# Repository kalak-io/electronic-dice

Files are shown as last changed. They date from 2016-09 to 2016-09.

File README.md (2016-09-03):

#D++

This is the electronic Project in 42 school made by [MDEKEN] (https://github.com/madeka)/ [DBISCHOF] (https://github.com/DimitriBischoff)/ [CJACQUEM] (https://github.com/kalak-io)

Great players we are, we love discovering new games. Most games require at least one dice if not other accessories. As part of the electronic program offered at the school 42, we wanted to design the object that would fit in all our games.

##Features

- Simple dice from 1 to 999
- Multiple dices from 1 to 9
- Countdown
- Chronometer

During six months, we learned :
- [x] to choose the right components ;
- [x] to draw the schematics ;
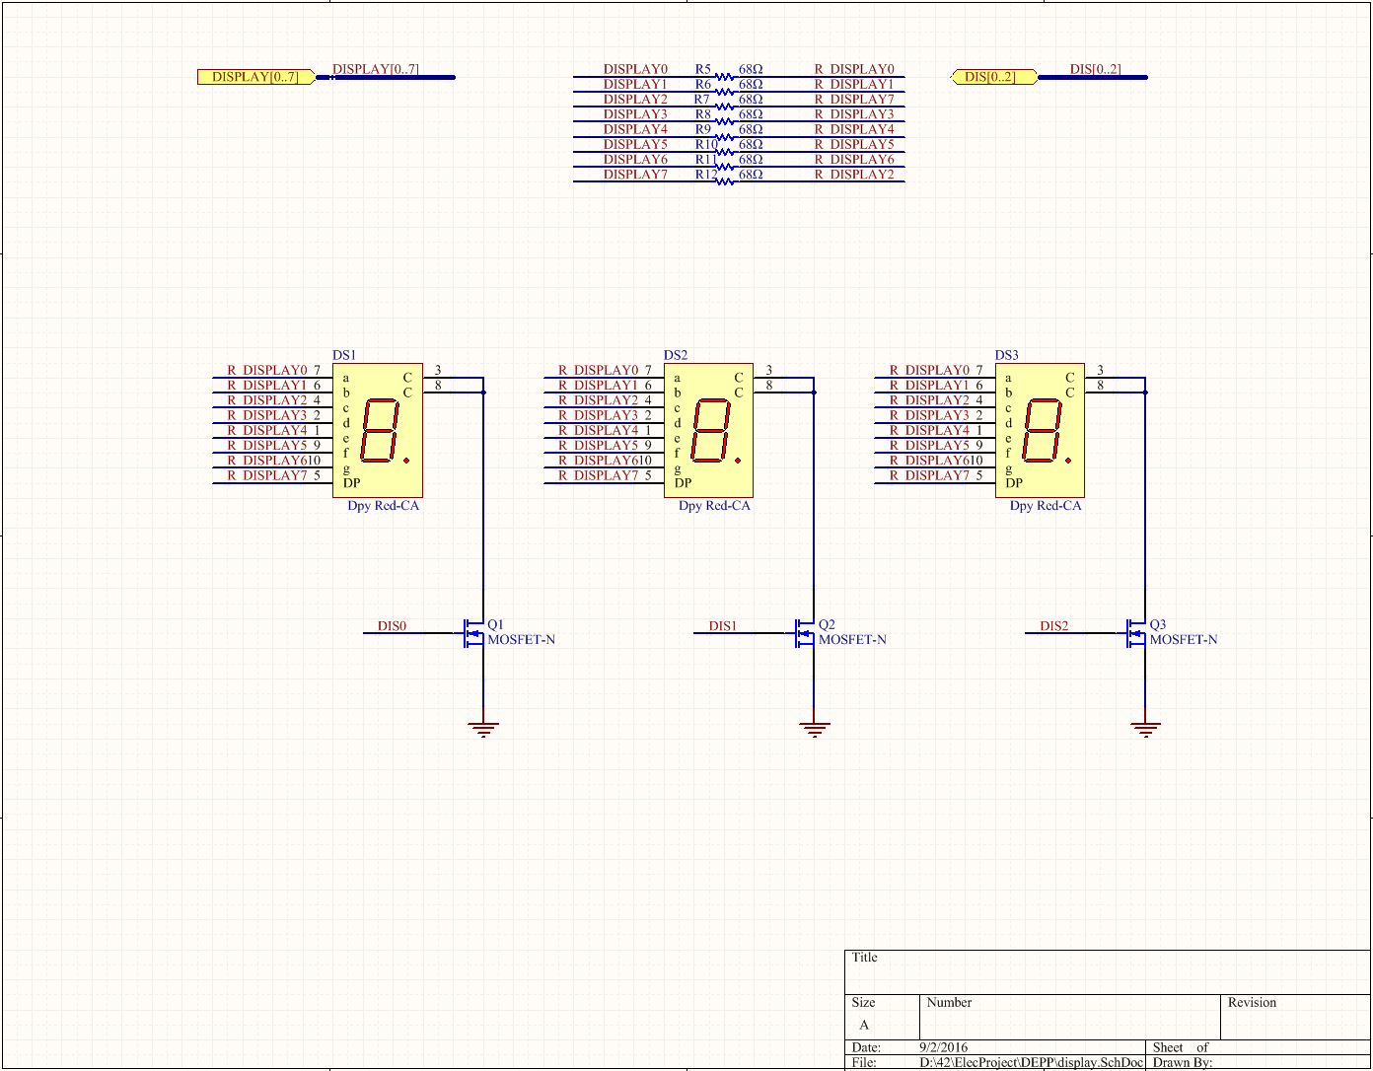
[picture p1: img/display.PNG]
Schematic

Schematics display
- [x] to design our own printed circuit board ;
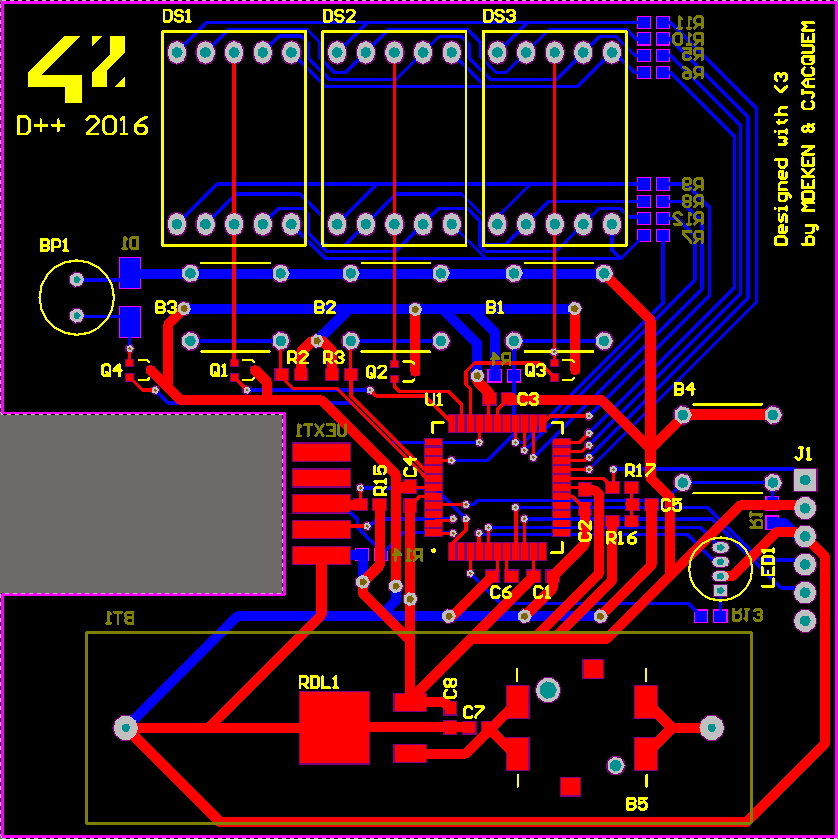
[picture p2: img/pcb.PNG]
pcb

- [x] to solder the components ;
- [x] to develop the features in C language ;
- [x] to test and to fix the code.

__We are happy to share with the community our work and we hope you'll have as much fun we had.__

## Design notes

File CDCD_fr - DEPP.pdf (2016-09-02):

D++

# Cahier des charges

élaboré dans le cadre du module d’électronique dispensé par Grégoire de

Turckheim au premier semestre 2016 à l’école 42

## Équipe

Dimitri Bischoff Madison Deken Clément Jacquemaire

D++

Cahier des charges | * | 2 / 8

INTRODUCTION

Grands joueurs de jeux de société, nous adorons découvrir de nouveau jeu voire d’en

créer. La plupart des jeux de société auxquels nous jouons nécessite au moins un dé si

ce n'est d'autres accessoires tel qu'un sablier. Dans le cadre du programme d'électronique

proposé à l'école 42, nous avons eu envie de concevoir l'objet qui permettrait de s'adapter

à tous nos jeux. Notre idée est un objet électronique pour nos activités ludiques qui devra

intégrer les fonctionnalités suivantes :

- Reproduire le comportement de un à trois dés gradués de 0 à 9 ;
- Avoir un chronomètre avec un temps maximal de 15 minutes ;
- Avoir un compte-à-rebours de 1 à 900 secondes, soit 15 minutes ;
- Émettre un son lors du lancer de dés et à la fin du compte-à-rebours.

Chacune de ces fonctionnalités sera exécutée seule. Il n'y aura pas de prise en charge

du multitâches. La sélection d'une fonctionnalité se fera par une interface de

paramétrages.

Les contraintes techniques posées sont :

- Miniaturiser au maximum notre objet pour qu'il soit transportable et à l'échelle

commune des accessoires de jeux de société ;

- Résister aux chocs d'intensité moyenne et aux accélérations ;
- Générer des résultats aléatoires pour chacun des afficheurs/dés ;
- Définir quand le calcul de l'aléatoire commence et s'arrête, sans doute dès qu'il est

mis en mouvement et quand il se stabilise.

EXPRESSION FONCTIONELLE

Notre objet comprendra quatre modes :

- un "dé simple" dont la plage des résultats potentiels est de 1 à 999 ;
- un "dé multiple" dont le nombre de dés activés peut varier de 1 à 3 et dont leur

plage des résultats potentiels varie de 1 à 9 ;

- un "chronomètre" ;
- un "compte-à-rebours".

À l'initialisation, le mode par défaut est celui du "dé simple".

Un bouton poussoir permet de choisir un mode différent. La progression dans les choix

possibles est signalée par une LED multicolore. Chaque mode ayant sa propre couleur

qui reste à définir.

Pour correspondre aux besoins de l'utilisateur, les modes "dé simple", "dé multiple" et

"compte-à-rebours" sont paramétrables.

DÉ SIMPLE

Par défaut, la plage des résultats potentiels s'étend de 1 à 6, soit les deux afficheurs de

gauche mis à zéro.

Pour modifier ce paramètre, l'utilisateur peut incrémenter la valeur maximale grâce à un

bouton situé sous chaque afficheur. Un premier clic de sécurité accompagné d'une

notification sonore suivi du clignotement de l'afficheur visé signifie à l'utilisateur qu'il peut

modifier la valeur maximale.

L'afficheur le plus à gauche modifie les centaines, celui du milieu les dizaines, celui de

droite les unités.

Leur plage de sélection s'étend de 0 à 9. Une incrémentation au-dessus de 9 fait repartir

l'affichage à 0.

Un lancer de dé permet de générer un nombre aléatoire dans la plage de résultats

potentiels entre 1 et X, X étant le nombre paramétré par l'utilisateur.

DÉ MULTIPLE

Par défaut, le nombre de dés activés est de 3 et la plage des résultats potentiels s'étend

de 1 à 6.

Pour modifier ces paramètres, l'utilisateur peut incrémenter la valeur maximale grâce à

un bouton situé sous chaque afficheur. Un premier clic de sécurité accompagné d'une

notification sonore suivi du clignotement de l'afficheur visé signifie à l'utilisateur qu'il peut

modifier la valeur maximale.

L'afficheur le plus à gauche modifie le premier dé, celui du milieu le deuxième dé, celui

de droite le dernier dé.

Leur plage de sélection s'étend de 0 à 9. Une incrémentation au-dessus de 9 fait repartir

l'affichage à 0. Un choix à 0 suspend le calcul de l'aléatoire pour cet afficheur / dé.

Un lancer de dé permet de générer un chiffre aléatoire pour chaque aléatoire dans la

plage de résultats potentiels entre 1 et X, X étant le chiffre paramétré par l'utilisateur. Les

plages sont indépendantes les unes des autres. Le premier dé peut aller de 1 à 6, le

deuxième de 1 à 4 et le dernier de 1 à 9.

COMPTE-À-REBOURS

Par défaut, le temps à décompter est de 30 secondes.

Pour modifier ce paramètre, l'utilisateur peut incrémenter la valeur maximale grâce à un

bouton situé sous chaque afficheur. Un premier clic de sécurité accompagné d'une

notification sonore suivi du clignotement de l'afficheur visé signifie à l'utilisateur qu'il peut

modifier la valeur maximale.

L'afficheur le plus à gauche modifie le nombre de minutes, celui du milieu les dizaines de

secondes, celui de droite les unités.

Leur plage de sélection s'étend de 0 à 9 pour l'afficheur de gauche et de droite ; l'afficheur

du milieu allant de 0 à 5 compris. Une incrémentation au-dessus de leur valeur maximale

fait repartir l'affichage à 0.

Un lancer de dé permet de lancer le compte-à-rebours.

Arrivé à 0, un son retentit pendant deux secondes.

CHRONOMÈTRE

Par défaut, les afficheurs affichent 0.

Pour lancer le chronomètre, il suffit d'appuyer sur le bouton situé sous l'afficheur gauche,

pour mettre en pause, il faut appuyer sur le bouton situé sous l'afficheur du milieu, pour

réinitialiser le chronomètre, sur le bouton situé sous l'afficheur de droite.

Un son est émis quand on appuie sur un de ces boutons.

L'afficheur de gauche désigne les minutes écoulées, celui du centre les dizaines de

secondes écoulées, celui de droite les secondes.

Leur plage d'affichage s'étend de 0 à 9 pour l'afficheur de gauche et de droite ; l'afficheur

du milieu allant de 0 à 5 compris.

MODE D’EMPLOI

AVERTISSEMENT: Pour réduire les risques d’incendie et de secousse électrique, ne pas exposer cet

appareil à la pluie ni à l’humidité.

GUIDE DE PRISE EN MAIN

Avec ce dé, vous êtes prêt à vivre des parties enflammées de jeux de société. Il va vous permettre d’avoir

un dé affichant une valeur aléatoire de 1 à 999, jusqu’à 3 dés affichant une valeur aléatoire de 1 à 9, mais

aussi un compte-à-rebours et un chronomètre. Ce dé peut vous accompagner dans 999 jeux !

1. | Appuyez sur le bouton On/Off pour mettre en marche le dé.
2. | Choisissez le mode de votre choix en appuyant sur le bouton choix des modes. Il existe quatre modes : des dés, un compte-à-rebours et un chronomètre. Chaque mode est représenté par une couleur. Rouge => Compte-à-rebours Violet => Dé multiple Bleu => Dé simple Vert => Chronomètre
2.1 | MODE DÉ SIMPLE : Entrez dans le mode de configuration en appuyant sur le bouton correspondant au bon écran à modifier. Choisissez la valeur maximale de votre choix en incrémentant successivement les centaines, les dizaines et les unités. Lancez le dé pour obtenir une valeur.
2.2 | MODE DÉ MULTIPLE : Entrez dans le mode de configuration en appuyant sur le bouton correspondant au bon écran à modifier. Choisissez la valeur maximale de votre choix en incrémentant successivement chacun des dés. Lancez le dé pour obtenir des valeurs.
2.3 | MODE COMPTE-À-REBOURS : Entrez dans le mode de configuration en appuyant sur le bouton correspondant au bon écran à modifier. Choisissez la durée de votre choix en incrémentant successivement les minutes, les dizaines de secondes et les secondes. Lancez simplement le dé pour démarrer le compte-à-rebours. ATTENTION : le compte-à-rebours ne va pas au-delà de 9 minutes et 59 secondes.
2.4 | MODE CHRONOMÈTRE : Lancez le chronomètre en appuyant sur le bouton situé sous l’afficheur central. Faites pause en appuyant sur le bouton central et celui de droite pour réinitialiser le chronomètre. ATTENTION : le chronomètre ne va pas au-delà de 9 minutes et 59 secondes.

CONTENU DE LA BOITE

- Un dé électronique
- Un mode d’emploi

ATTENTION : Les éléments d’emballage tels que films plastiques, rubans adhésifs, étiquettes et rubans de

fixation métalliques ne font pas partie de ce jouet et doivent être enlevés pour raison de sécurité avant toute

utilisation par un enfant.

ALIMENTATION

Le dé fonctionne avec 1 pile lithium 3V7 de type AA (non fournie).

Ne pas recharger les piles non rechargeables. Retirer les accumulateurs du jeu avant de les recharger. Ne

charger les accumulateurs que sous la surveillance d’un adulte. Ne pas mélanger différents types de piles

ou accumulateurs, ou des piles et accumulateurs neufs et usagés. Les piles et accumulateurs doivent être

mis en place en respectant la polarité. Les piles et accumulateurs usagés doivent être enlevés du jouet.

Les bornes d’une pile ou d’un accumulateur ne doivent pas être mises en court-circuit. Ne pas jeter les piles

au feu. Retirer les piles en cas de non utilisation prolongée. ATTENTION : D’importantes interférences

électromagnétiques ou des décharges électrostatiques peuvent provoquer un dysfonctionnement ou une

perte de données. Si l’appareil ne fonctionne pas correctement, réinitialisez l’unité ou enlevez puis remettez

les piles.

ENTRETIEN

Protéger le dé de l’humidité. S’il est mouillé, l’essuyer immédiatement. Ne pas le laisser en plein soleil, ne

pas l’exposer à une source de chaleur. Ne pas le laisser tomber. Ne pas tenter de le démonter. Pour le

nettoyer, utiliser un chiffon légèrement imbibé d’eau à l’exclusion de tout produit détergent. En cas de

mauvais fonctionnement, essayez d’abord de changer les piles. Si le problème persiste, relisez

attentivement la notice afin de vérifier que rien ne vous a échappé.

GARANTIE

NOTE : Veuillez garder ce mode d’emploi, il contient d’importantes informations. Ce produit est couvert par

notre garantie de zéro année. Pour toute mise en œuvre de la garantie ou de service après-vente, vous

devez vous adresser à Grégoire. Notre garantie ne couvre pas les vices de matériel ou de montage

imputables au constructeur à l’exclusion de toute détérioration provenant du non-respect de la notice

d’utilisation ou toute intervention intempestive sur l’article (telle que le démontage, exposition à la chaleur

ou à l’humidité).

Il est recommandé de conserver l’emballage pour toute référence ultérieure. Dans un souci constant

d’amélioration, nous pouvons être amenés à modifier les couleurs et les détails du produit présenté sur

l’emballage. Avertissement ! Ce dé ne convient pas à un enfant de moins de 36 mois. Risque d’étouffement.

CONTACT

D++
96 boulevard Bessières
75017 Paris
France

Services consommateurs demandez Matthieu.

Informations sur la protection de l’environnement : Tout appareil électrique usé est une matière recyclable et

ne devrait pas faire partie des ordures ménagères! Nous vous demandons de bien vouloir nous soutenir en

contribuant activement au ménagement des ressources et à la protection de l’environnement en déposant cet

appareil dans des de collecte (si existants).

Conçu en France – Fabriqué en Chine

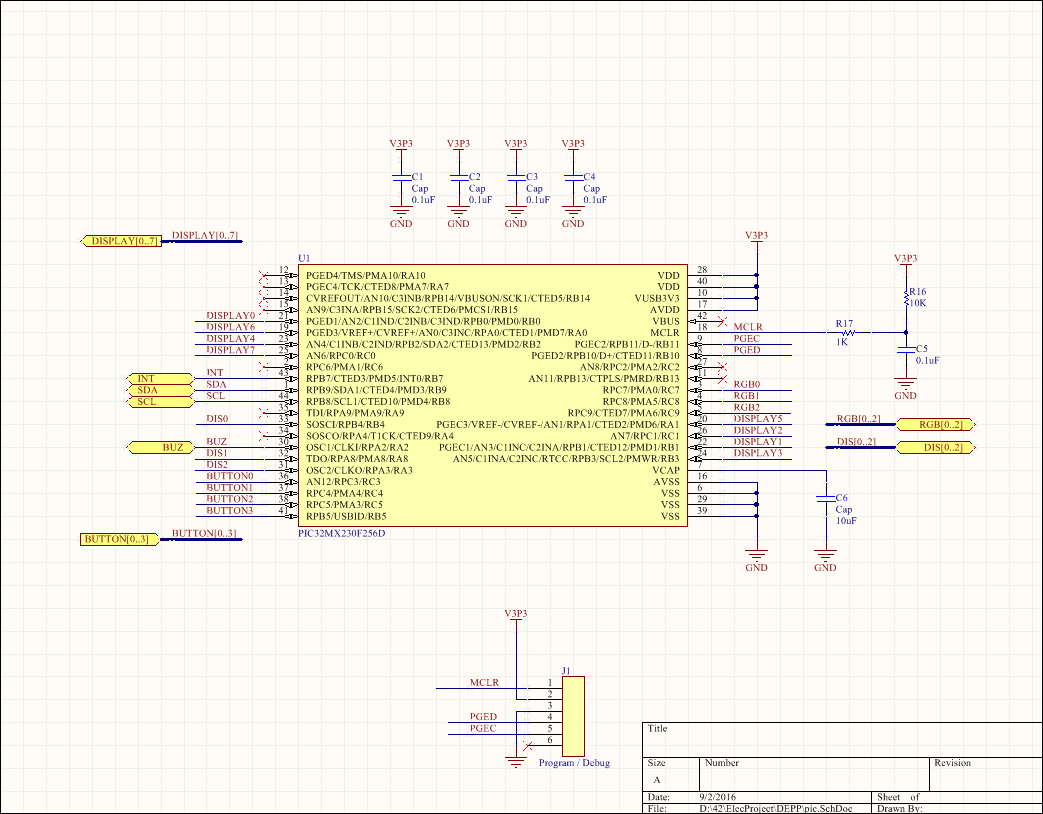
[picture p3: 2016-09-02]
img/schematic-pic.PNG

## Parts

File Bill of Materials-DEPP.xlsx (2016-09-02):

Comment | Description | Designator | Footprint | LibRef | Quantity | Fabricant | Fournisseur | Ref. fabricant | Ref. fournisseur
PIC32MX320F032H-40I/PT |  | U2 |  | PIC32MX320F032H-40I/PT | 1 | MICROCHIP | Farnell | PIC32MX320F032H-40I/PT | 1523318
Program / Debug |  | J1 | RJ12_90 | CON6 | 1 | Molex
Dpy Blue-CA | 14.2 mm General Purpose Blue 7-Segment Display: CA, RH DP, Gray Surface | DS1 | H | Dpy Blue-CA | 1 | AVAGO TECHNOLOGIES | Farnell | HDSM-433B | 1659317
Dpy Red-CA | 7.62 mm Black Surface HER 7-Segment Display: CA, RH DP | DS2 | A | Dpy Red-CA | 1 | AVAGO TECHNOLOGIES | Farnell | HDSM-433C | 1651429
Dpy Red-CA | 7.62 mm Black Surface HER 7-Segment Display: CA, RH DP | DS3 | A | Dpy Red-CA | 1 | AVAGO TECHNOLOGIES | Farnell | HDSM-433C | 1651429
MMA7660FC | Accelerometer | A1 |  | MMA7660FC | 1 | Freescale / NXP | Farnell | MMA7660FCT | 2238133
Buzzer Piezo | Buzzer piezo | BP1 | PIN2 | Speaker | 1 | PRO SIGNAL | Farnell | ABT-410-RC | 1022402
8MHz | Crystal Oscillator | Y1 | XTAL139X50X45 | XTAL | 1 | FOX ELECTRONICS | Farnell | FOXSDLF/080-20 | 2063972
'VLF302515MT-2R2M' | Inductance | L1 |  | 'VLF302515MT-2R2M' | 1 | TDK | Farnell | VLF302515MT-2R2M | 2455323
LED RGB | LED RGB pour les modes | LED |  | LED RGB | 1 | MULTICOMP | Farnell | 703-1028 | 2112143
3V | Multicell Battery | BT1 | BAT-2 | Battery | 1 | MULTICOMP | Farnell | CR2450 | 2065173
3V | Multicell Battery | BT2 | BAT-2 | Battery | 1 | MULTICOMP | Farnell | CR2450 | 2065173
MOSFET-N | N-Channel MOSFET | Q1 | E3 | MOSFET-N | 1 | NXP | Farnell | NX7002AKA | 2357126
MOSFET-N | N-Channel MOSFET | Q2 | E3 | MOSFET-N | 1 | NXP | Farnell | NX7002AKA | 2357126
MOSFET-N | N-Channel MOSFET | Q3 | E3 | MOSFET-N | 1 | NXP | Farnell | NX7002AKA | 2357126
TPS62150ARGTR | Regulateur a decouplage | U1 |  | TPS62150ARGTR | 1 | Texas Instruments | Farnell | TPS62150ARGTT | 2361248
SW-SPST | Single-Pole, Single-Throw Switch | S2 | SPST-2 | SW-SPST | 1 | C & K COMPONENTS | Farnell | PVB4 EE 300 NS LFS | 2435330
 | Support de pile |  |  | KEYSTONE 1025-7 BATTERY HOLDER PCB | 1 | KEYSTONE | Farnell | 1025-7 | 1650668
SW-PB | Switch | S1_BUTTON | SPST-2 | SW-PB | 1 | PANASONIC ELECTRONIC COMPONENTS | Farnell | ESE20C341 | 2079611
SW-PB | Switch | S1_BUTTON0 | SPST-2 | SW-PB | 1 | PANASONIC ELECTRONIC COMPONENTS | Farnell | ESE20C341 | 2079611
SW-PB | Switch | S1_BUTTON1 | SPST-2 | SW-PB | 1 | PANASONIC ELECTRONIC COMPONENTS | Farnell | ESE20C341 | 2079611
SW-PB | Switch | S1_BUTTON3 | SPST-2 | SW-PB | 1 | PANASONIC ELECTRONIC COMPONENTS | Farnell | ESE20C341 | 2079611

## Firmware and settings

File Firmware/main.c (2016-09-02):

#include "depp.h"
#include <p32xxxx.h>

u8 mode = SIMPLE;
u8 max_ds1 = 6;
u8 max_ds2 = 6;
u8 max_ds3 = 6;
u16 absolute_max = 6;
u8 current_ds1 = 0;
u8 current_ds2 = 0;
u8 current_ds3 = 6;
u8 current_time = 0;
u8 default_count = 30;
u8 default_min = 0;
u8 default_chrono = 0;
u8 chrono = 0;
u16 counter_tmr = 0;
u8 dp = 0;
u8 minute = 0;
u32 random_value1 = 0; //u32 in order to avoid overflow
u32 random_value2 = 0;
u32 random_value3 = 0;
s16 x = 0;
s16 y = 0;
s16 z = 0;
u8 blink = 0;

void set_number(u16 n) {
    current_ds1 = n / 100;
    current_ds2 = n % 100 / 10;
    current_ds3 = n % 10;
}

void show_result() {
    u8 result = 0;

    blink = 0;
    if (mode == SIMPLE) {
        if (absolute_max != 0) {
            random_value1 %= absolute_max;
            random_value2 %= absolute_max;
            random_value3 %= absolute_max;
            result = ((random_value1 + random_value2 + random_value3) % absolute_max) + 1;
            set_number(result);
        }
    } else if (mode == MULTI) {
        current_ds1 = (max_ds1 > 0) ? (random_value1 % max_ds1) + 1 : 0;
        current_ds2 = (max_ds2 > 0) ? (random_value2 % max_ds2) + 1 : 0;
        current_ds3 = (max_ds3 > 0) ? (random_value3 % max_ds3) + 1 : 0;
    } else if (mode == COUNTDOWN && chrono == 0) {
        chrono = 1;
    }
}

void __ISR(INT1_VECTOR, ipl1SOFT) Button2_handler(void) {
    while (PORTCbits.RC4 == 1);
    while (PORTCbits.RC4 == 1);
    counter_tmr = 0;
    if (mode == SIMPLE) {
        if (blink == 1) {
            ++current_ds2;
            if (current_ds2 >= 10)
                current_ds2 = 0;
            absolute_max = (current_ds1 * 100) + (current_ds2 * 10) + current_ds3;
            set_number(absolute_max);
        } else
        {
            blink = 1;
            set_number(absolute_max);
        }
    } else if (mode == MULTI) {
        if (blink == 1) {
            ++max_ds2;
            if (max_ds2 >= 10)
                max_ds2 = 0;
            set_number((max_ds1 * 100) + (max_ds2 * 10) + max_ds3);
        } else{
            blink = 1;
            set_number((max_ds1 * 100) + (max_ds2 * 10) + max_ds3);
        }
    } else if (mode == COUNTDOWN) {
        if (PORTCbits.RC5 == 1) {
            current_time = default_count;
            set_number(current_time);
        } else if (chrono == 0) {
            if (blink == 1) {
                ++current_ds2;
                if (current_ds2 >= 6)
                    current_ds2 = 0;
                default_count = (current_ds2 * 10) + current_ds3;
                current_time = default_count;
                set_number((default_min * 100) + default_count);
            } else{
                blink = 1;
                set_number((default_min * 100) + default_count);
            }
        }
    } else if (mode == CHRONO) {
        chrono = (chrono == 1) ? 0 : 1;
    }
    IFS0bits.INT1IF = 0;
}

void __ISR(INT2_VECTOR, ipl2SOFT) Button1_handler(void) {
    while (PORTCbits.RC3 == 1);
    while (PORTCbits.RC3 == 1);
    counter_tmr = 0;
    if (mode == SIMPLE) {
        if (blink == 1) {
            ++current_ds3;
            if (current_ds3 >= 10)
                current_ds3 = 0;
            absolute_max = (current_ds1 * 100) + (current_ds2 * 10) + current_ds3;
            set_number(absolute_max);
        } else
        {
            blink = 1;
            set_number(absolute_max);
        }
    } else if (mode == MULTI) {
        if (blink == 1) {
            ++max_ds3;
            if (max_ds3 >= 10)
                max_ds3 = 0;
            set_number((max_ds1 * 100) + (max_ds2 * 10) + max_ds3);
        } else{
            blink = 1;
            set_number((max_ds1 * 100) + (max_ds2 * 10) + max_ds3);
        }
    } else if (mode == COUNTDOWN) {
        if (chrono == 0) {
            if (blink == 1) {
                ++current_ds3;
                if (current_ds3 >= 10)
                    current_ds3 = 0;
                current_time = (current_ds2 * 10) + current_ds3;
                default_count = current_time;
                set_number((default_min * 100) + default_count);
            } else{
                blink = 1;
                set_number((default_min * 100) + default_count);
            }
        } else
            chrono = 0;
    }
    IFS0bits.INT2IF = 0;
}

void __ISR(INT3_VECTOR, ipl2SOFT) Mode_handler(void) {
    chrono = 0;
    blink = 0;
    while (PORTBbits.RB5 == 1);
    while (PORTBbits.RB5 == 1);
    mode = (mode + 1) % 4;
    if (mode == SIMPLE) {
        dp = 0;
        set_number(absolute_max);
        pwm_led(BLUE);
    } else if (mode == MULTI) {
        dp = 0;
        set_number((max_ds1 * 100) + (max_ds2 * 10) + max_ds3);
        pwm_led(PURPLE);
    } else if (mode == COUNTDOWN) {
        dp = 1;
        current_time = 30;
        counter_tmr = 0;
        set_number((default_min * 100) + default_count);
        pwm_led(RED);
    } else if (mode == CHRONO) {
        dp = 1;
        current_time = 0;
        counter_tmr = 0;
        set_number(default_chrono);
        pwm_led(GREEN);
    }
    while (PORTBbits.RB5 == 1);
    IFS0bits.INT3IF = 0;
}

void __ISR(INT4_VECTOR, ipl1SOFT) Button3_handler(void) {
    while (PORTCbits.RC5 == 1);
    while (PORTCbits.RC5 == 1);
    counter_tmr = 0;
    if (mode == SIMPLE) {
        if (blink == 1) {
            dp = 0;
            ++current_ds1;
            if (current_ds1 >= 10)
                current_ds1 = 0;
            absolute_max = (current_ds1 * 100) + (current_ds2 * 10) + current_ds3;
            set_number(absolute_max);
        } else{
            blink = 1;
            set_number(absolute_max);
        }
    } else if (mode == MULTI) {
        if (blink == 1) {
            dp = 0;
            ++max_ds1;
            if (max_ds1 >= 10)
                max_ds1 = 0;
            set_number((max_ds1 * 100) + (max_ds2 * 10) + max_ds3);
        } else{
            blink = 1;
            set_number((max_ds1 * 100) + (max_ds2 * 10) + max_ds3);
        }
    } else if (mode == COUNTDOWN) //reset to default value
    {
        if (PORTCbits.RC4 == 1) {
            current_time = default_count;
            set_number(current_time);
        } else if (chrono == 0) {
            if (blink == 1) {
                ++default_min;
                if (default_min >= 10)
                    default_min = 0;
                minute = default_min;
                set_number((default_min * 100) + (current_ds2 * 10) + current_ds3);
            } else{
                set_number((default_min * 100) + default_count);
                blink = 1;
            }
        }
    } else if (mode == CHRONO) //reset to default value
    {
        chrono = 0;
        current_time = 0;
        set_number(current_time);
    }
    IFS0bits.INT4IF = 0;
}

u8 mpu_is_shaking() {
    static u8 stock_stack = 0;
    u8 ret = 0;

    x = (i2c_read(ACCEL_XOUT_H) << 8) + i2c_read(ACCEL_XOUT_L);
    y = (i2c_read(ACCEL_YOUT_H) << 8) + i2c_read(ACCEL_YOUT_L);
    z = (i2c_read(ACCEL_ZOUT_H) << 8) + i2c_read(ACCEL_ZOUT_L);
    
    if ((x / 8192 <= -2 || 2 <= x / 8192) ||
            (y / 8192 <= -2 || 2 <= y / 8192) ||
            (z / 8192 <= -2 || 2 <= z / 8192)) {
        ++stock_stack;
        if (stock_stack % 3 == 0)
            random_value1 = x + y + z;
        else if (stock_stack % 3 == 1)
            random_value2 = x + y + z;
        else if (stock_stack % 3 == 2)
            random_value3 = x + y + z;
    } else {
        ret = stock_stack >= 10 ? 1 : 0;
        stock_stack = 0;
    }
    return (ret);
}

void __ISR(TMR1_VECTOR, ipl3SOFT) Tmr1_handler(void) //TRM1 allows switch between DS1 & DS2
{
    ++counter_tmr;
    if (blink == 0 || (blink == 1 && counter_tmr % 5 == 1)) {
        if (LATAbits.LATA10 == 1) {
            MOS_OFF(A, 10);
            //    MOS_OFF(B, 14);
            MOS_ON(B, 15);
            putnbr(current_ds1, dp);
        } else if (LATBbits.LATB15 == 1) {
            //    MOS_OFF(A, 10);
            MOS_OFF(B, 15);
            MOS_ON(B, 14);
            putnbr(current_ds2, 0);
        } else if (LATBbits.LATB14 == 1) {
            MOS_OFF(B, 14);
            //    MOS_OFF(B, 15);
            MOS_ON(A, 10);
            putnbr(current_ds3, 0);
        }
    }
    if (counter_tmr > 15 && (mode == COUNTDOWN || mode == SIMPLE || mode == MULTI)) {
        if (mpu_is_shaking() == 1) {
            show_result();
        }
    }
    if (blink == 1 && counter_tmr > 400) {
        blink = 0;
        counter_tmr = 0;
    }
    if (counter_tmr > 200 && mode == COUNTDOWN && chrono == 1 && blink == 0) {
        counter_tmr = 0;
        if (current_time == 0) {
            if (minute != 0) {
                --minute;
                current_time = 59;
            } else
                chrono = 0;
        } else
            --current_time;
        set_number(minute * 100 + current_time);
    } else if (counter_tmr > 200 && mode == CHRONO && chrono == 1 && blink == 0) {
        counter_tmr = 0;
        if (current_time < 59)
            ++current_time;
        else {
            if (current_ds1 < 9) {
                ++current_ds1;
                current_time = 0;
            }
        }
        counter_tmr = 0;
        set_number(current_ds1 * 100 + current_time);
    }
    IFS0bits.T1IF = 0;
}

int main() {
    u16 delay = 1000;

    while (--delay > 0);
    generate_9clock();
    init_port();
    i2c_init();
    init_mpu();
    init_interrupt();
    init_pwm();

    DDPCONbits.JTAGEN = 0;
    pwm_led(BLUE);
    while (1) {
    }
}

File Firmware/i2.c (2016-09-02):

#include "depp.h"

void    generate_9clock()
{
    u8  clock = 0;

    LATBbits.LATB8 = 0;
    TRIS_OUT(B, 8);
    while (clock < 9)
    {
        if (LATBbits.LATB8 == 1)
        {
            LAT_OFF(B, 8);
            clock++;
        }
        else
            LAT_ON(B, 8);
    }
}

void    i2c_init()
{
    I2C1CONbits.ON = 1;     //Turn i2c ON
    I2C1BRG = 0x3;           //Set baudrate		// SOURCE ERREUR
}

void    i2c_transmit(u8 addr)
{
    I2C1TRN = addr;                   //Adress to transfer
    while (I2C1STATbits.TRSTAT || I2C1STATbits.TBF)        
        ;
    if (!I2C1STATbits.ACKSTAT)
        ;
}

void    i2c_start()
{
    I2C1CONbits.SEN = 1;                    //Assert start condition on SDA SCL
    while (I2C1CONbits.SEN)                 
        ;
}

void    i2c_repeat_start()
{
    I2C1CONbits.RSEN = 1;		    //Assert repeated start
    while (I2C1CONbits.RSEN == 1);	    //Wait until RSEN is cleared
}

void    i2c_stop()
{
    I2C1CONbits.PEN = 1;        //Generates STOP
    while (I2C1CONbits.PEN == 1);
}

void    i2c_getadress(u8 rw_bit)
{
    i2c_transmit((0x68 << 1) | rw_bit);     //Adress to the buffer
}

void    i2c_send_ack(u8 ack)
{
    I2C1CONbits.ACKDT = ack;
    I2C1CONbits.ACKEN = 1;      //Master generates ACK or NACK (ack -> 0 nack -> 1)
    while (I2C1CONbits.ACKEN == 1);
}

u8  i2c_receive()                   
{
    I2C1CONbits.RCEN = 1;       //Enable master reception
    while (!I2C1STATbits.RBF)  
        ;
    while (I2C1CONbits.RCEN == 1);
    return I2C1RCV;
}

u8 i2c_read(u8 amslave)
{
    u8 data = 0;

    i2c_start();                // bit start
    i2c_getadress(0);           // envoi adresse du 6 axis mode write

    i2c_transmit(amslave);      // envoi adresse du registre

    i2c_repeat_start();         // bit de restart
    i2c_getadress(1);           // envoi adresse de 6 axis mode read

    data = i2c_receive();       // lecture du registre
    i2c_send_ack(1);            // not ack
    i2c_stop();                 // bit stop

    return (data);
}

u16 i2c_read16(u8 amslave)
{
    u16 data = 0;

    i2c_start();             // bit start
    i2c_getadress(0);           // envoi adresse du 6 axis mode write

    i2c_transmit(amslave);            // envoi adresse du registre

    i2c_repeat_start();           // bit de restart
    i2c_getadress(1);           // envoi adresse de 6 axis mode read

    data = i2c_receive() << 8;           // lecture du registre
    i2c_send_ack(0);                  // ack
    data += i2c_receive();
    i2c_send_ack(1);                  // not ack
    i2c_stop();              // bit stop

    return (data);
}

void    i2c_write(u8 amslave, u8 value)
{
    i2c_start();
    i2c_getadress(0);           // envoi adresse du 6 axis mode write

    i2c_transmit(amslave);
    
    i2c_transmit(value);
    i2c_stop();
}

void    i2c_write16(u8 amslave, u16 value)
{
    i2c_getadress(0);
    i2c_transmit(amslave); 
    i2c_transmit(value >> 8);
    i2c_transmit(value);
    i2c_stop();
}
